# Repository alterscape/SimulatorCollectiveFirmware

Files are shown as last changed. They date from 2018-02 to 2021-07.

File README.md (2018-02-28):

# Simulator Collective Firmware

This repo contains firmware for a DIY simulator collective. The intent is not to commercialize, but rather to design something usable that an interested hobbyist with a relatively limited fabrication setup (ie: yours truly) can build and customize. Because I'm an aviation simulation enthusiast who likes physically correct (or as close as I can get for affordable prices) switchology, the "head" or "button box" component is designed to be interchangeable to support different airframes' controls. So far there are two software components:

## Collective Base

This firmware is intended to run on a Teensy 3.x, with the Joystick USB profile. It uses a contactless hall effect sensor to measure the collective arm's angle, and integrates input from the interchangeable button box. In future hardware/software revisions I hope to connect a twist throttle and collective brake as well.

## Collective Button Box

This firmware interfaces switches with the Base as an I2C slave. I probably could've used 74HC165 shift registers, like the Thrustmaster Cougar/Warthog, and just put all the brains in the Collective Base, but I like the idea of being able to support joystick axes (eg: for the spotlight slew control on some DCS helicopters) and for the box to be able to report things like its intended range of motion to the base.

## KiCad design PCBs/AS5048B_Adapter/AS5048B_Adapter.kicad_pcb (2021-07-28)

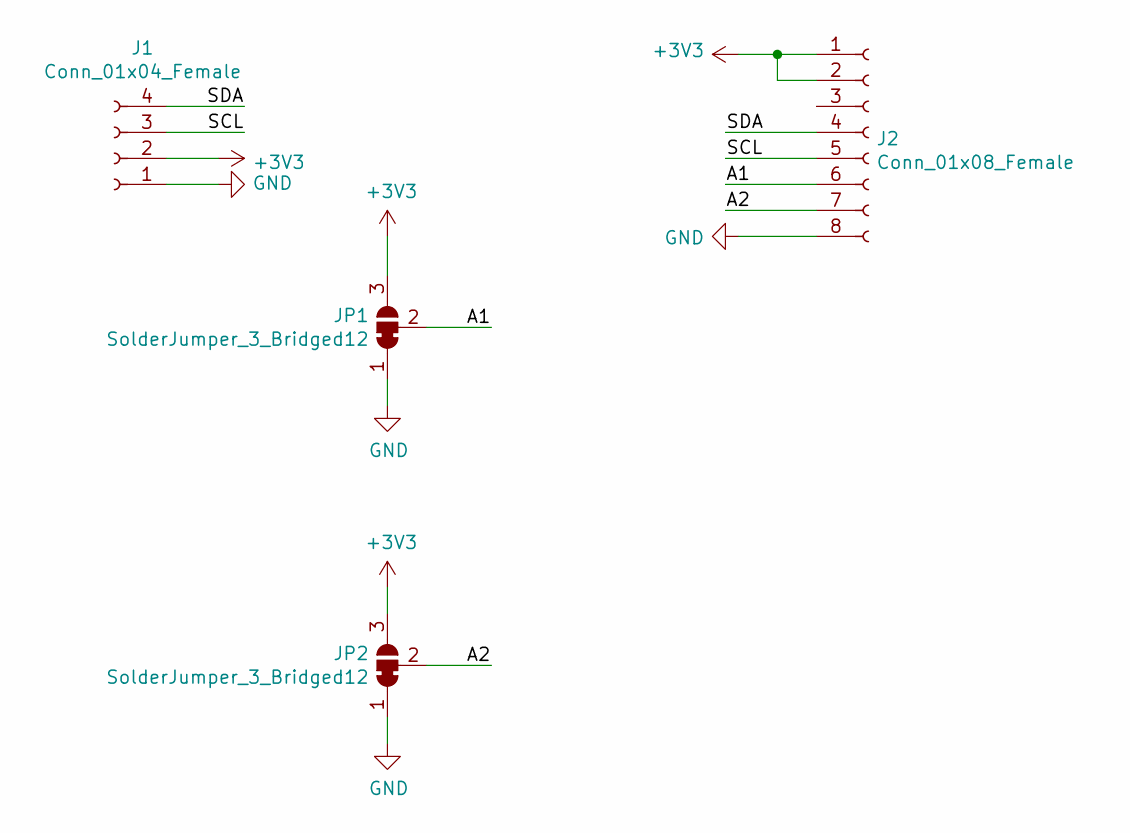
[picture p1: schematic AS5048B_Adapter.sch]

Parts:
J1: Conn_01x04_Female; Molex_PicoBlade_53047-0410_04x1.25mm_Straight
J2: Conn_01x08_Female; PinHeader_1x08_P2.54mm_Vertical
JP1, JP2: SolderJumper_3_Bridged12; SolderJumper-3_P1.3mm_Bridged12_Pad1.0x1.5mm

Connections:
+3V3: J1.2, J2.1, J2.2, JP1.3 (B), JP2.3 (B)
/A1: J2.6, JP1.2 (C)
/A2: J2.7, JP2.2 (C)
/SCL: J1.3, J2.5
/SDA: J1.4, J2.4
GND: J1.1, J2.8, JP1.1 (A), JP2.1 (A)

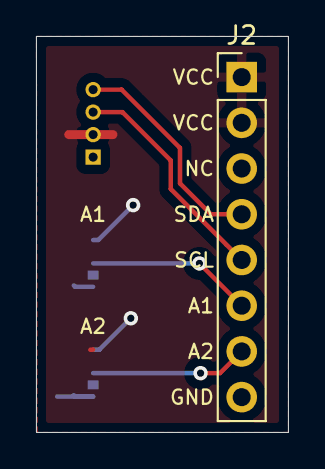
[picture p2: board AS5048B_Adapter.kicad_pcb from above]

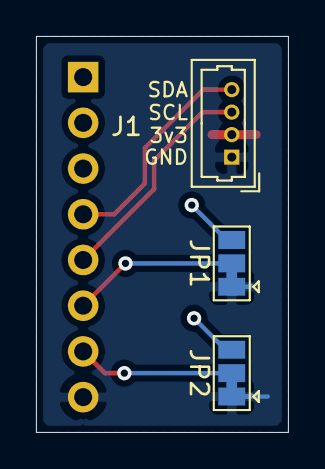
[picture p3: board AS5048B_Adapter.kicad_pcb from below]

Board: 2 copper layers, 14.0 x 22.0 mm, 4 parts (3 on the bottom side), 6 nets.

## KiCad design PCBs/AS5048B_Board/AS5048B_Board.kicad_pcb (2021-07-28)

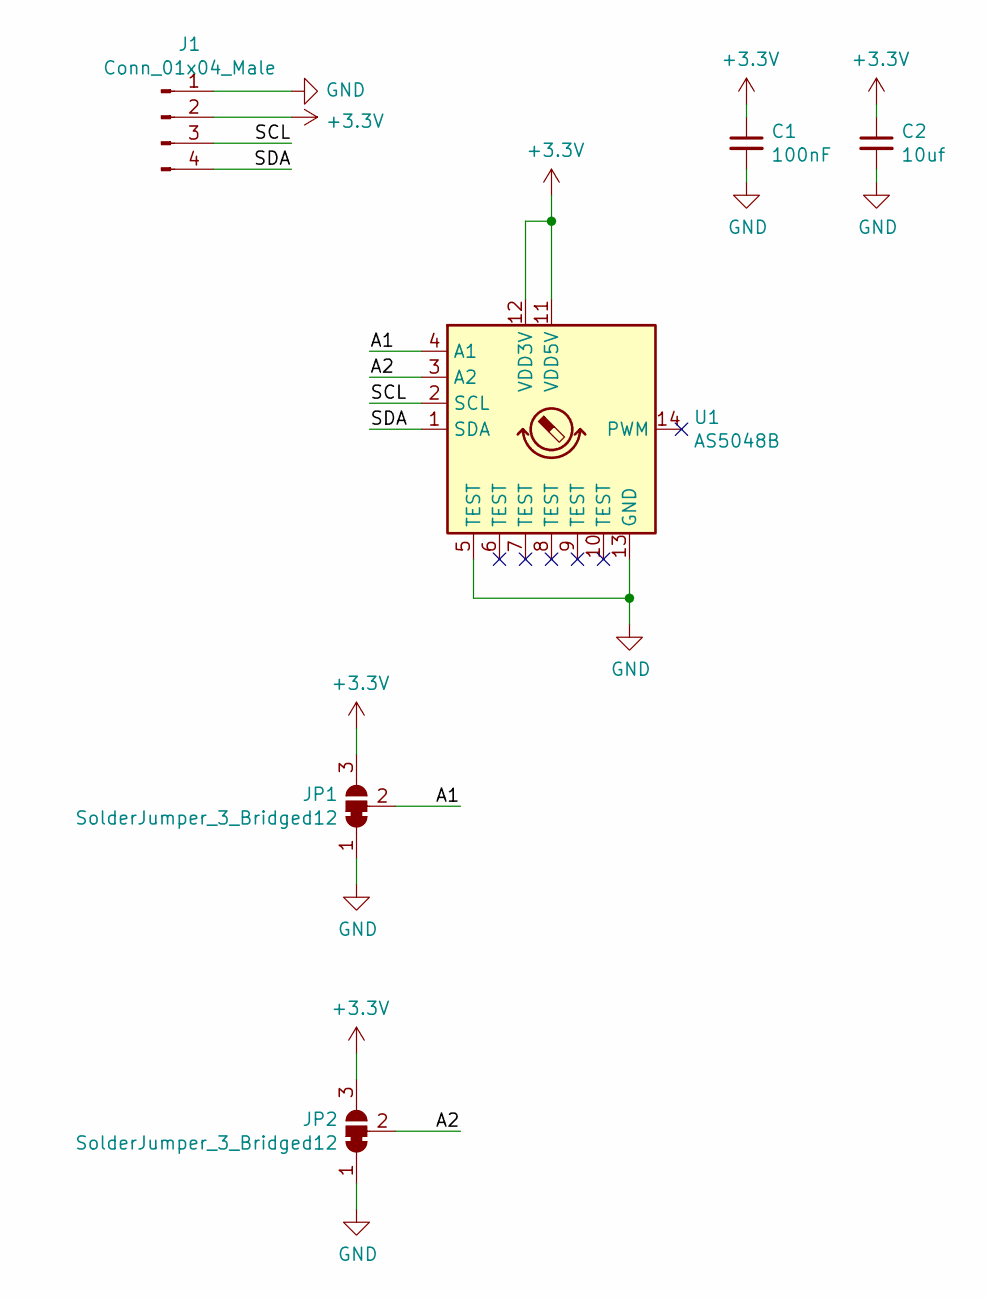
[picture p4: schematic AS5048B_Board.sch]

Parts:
C1: 100nF; C_0603_HandSoldering
C2: 10uf; C_0603_HandSoldering
J1: Conn_01x04_Male; Molex_PicoBlade_53047-0410_04x1.25mm_Straight
JP1, JP2: SolderJumper_3_Bridged12; SolderJumper-3_P1.3mm_Bridged12_Pad1.0x1.5mm
U1: AS5048B; TSSOP-14_4.4x5mm_P0.65mm

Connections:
+3V3: C1.1, C2.1, J1.2, JP1.3 (B), JP2.3 (B), U1.11 (VDD5V), U1.12 (VDD3V)
/A1: JP1.2 (C), U1.4 (A1)
/A2: JP2.2 (C), U1.3 (A2)
/SCL: J1.3, U1.2 (SCL)
/SDA: J1.4, U1.1 (SDA)
GND: C1.2, C2.2, J1.1, JP1.1 (A), JP2.1 (A), U1.5 (TEST), U1.13 (GND)

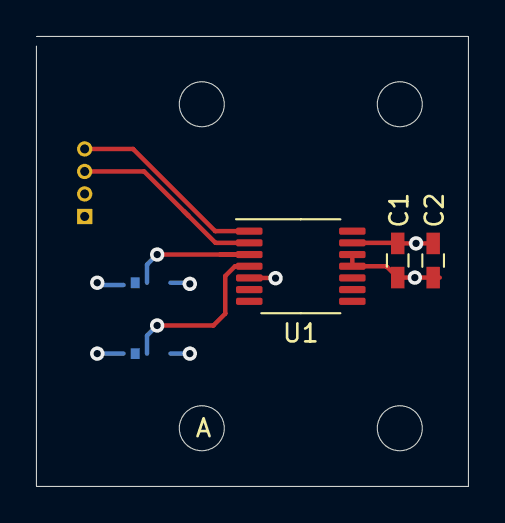
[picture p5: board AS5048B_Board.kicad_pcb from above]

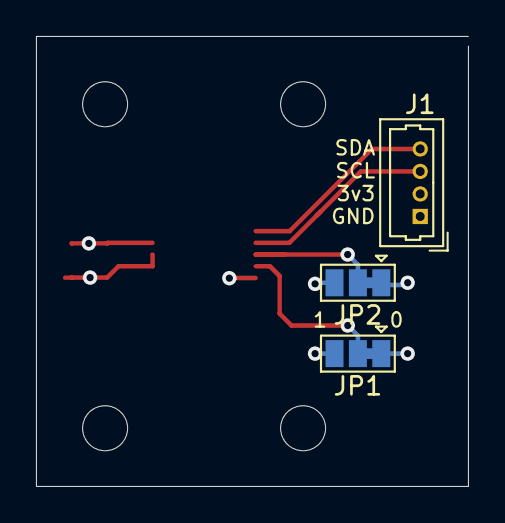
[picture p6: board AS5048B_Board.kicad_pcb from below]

Board: 4 copper layers, 24.0 x 25.0 mm, 8 parts (3 on the bottom side), 6 nets.

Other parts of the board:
A: MountingHole_2.5mm
B: MountingHole_2.5mm

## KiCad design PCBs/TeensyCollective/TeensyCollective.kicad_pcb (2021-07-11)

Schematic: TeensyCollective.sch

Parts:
C1: 47u; CP_Elec_4x4.5
C2, C4: 0.1uf; C_0603_HandSoldering
C3, C5: 1uf; C_0603_HandSoldering
D1: 1N4001; D_DO-41_SOD81_P7.62mm_Horizontal
FB1: Tiny; R_0603_HandSoldering
H1, H2, H3: MountingHole; MountingHole_2.2mm_M2_DIN965
J1: Barrel_Jack_MountingPin; BARREL_JACK
J2, J7: Conn_01x03; Molex_PicoBlade_53047-0310_03x1.25mm_Straight
J3, J4, J6: Conn_01x04; Molex_PicoBlade_53047-0410_04x1.25mm_Straight
J5: Conn_01x02; PinHeader_1x02_P2.54mm_Vertical
Q1: FQP30N06L; TO-220
R1, R2: 470; R_0603_HandSoldering
R3: R_Small_US; R_0603_HandSoldering
R4: 10k; R_0603_HandSoldering
R5, R6: 0; R_0603_HandSoldering
U1: Teensy3.2; Teensy30_31_32_LC_EDGE_ONLY

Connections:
+3V3: C2.1, C5.1, J2.2, J3.2, J4.2, J6.2, J7.2, R1.1, R2.2, U1.31
+5V: C1.1, D1.1, FB1.1, J1.1, J5.1
/BRAKE_PWM: R3.2, U1.8
/I1: J2.3, R6.1
/I2: J7.3, R5.2
/SCL: J3.3, J4.3, J6.3, R2.1, U1.26
/SDA: J3.4, J4.4, J6.4, R1.2, U1.25
GND: C1.2, C2.2, C3.2, C4.2, C5.2, J1.2, J2.1, J3.1, J4.1, J6.1, J7.1, Q1.3, R4.1, U1.1
unnamed: C3.1, C4.1, FB1.2, U1.33
unnamed: D1.2, J5.2, Q1.2
unnamed: Q1.1, R3.1, R4.2
unnamed: R5.1, U1.9
unnamed: R6.2, U1.10

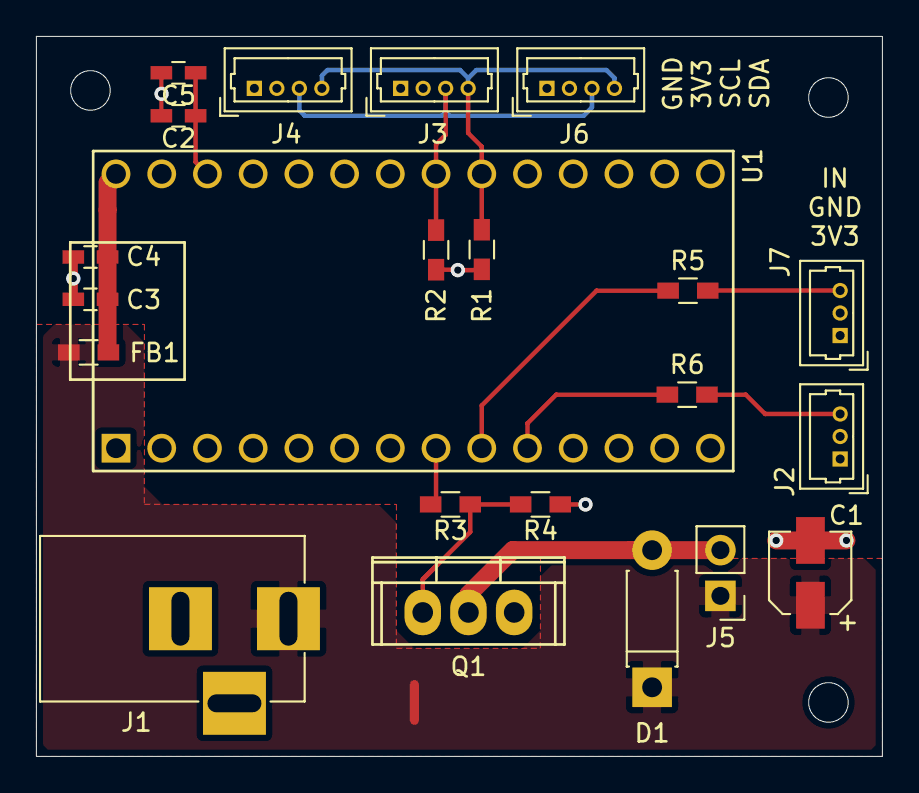
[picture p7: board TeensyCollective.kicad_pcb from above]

Board: 4 copper layers, 47.0 x 40.0 mm, 25 parts (0 on the bottom side), 13 nets.

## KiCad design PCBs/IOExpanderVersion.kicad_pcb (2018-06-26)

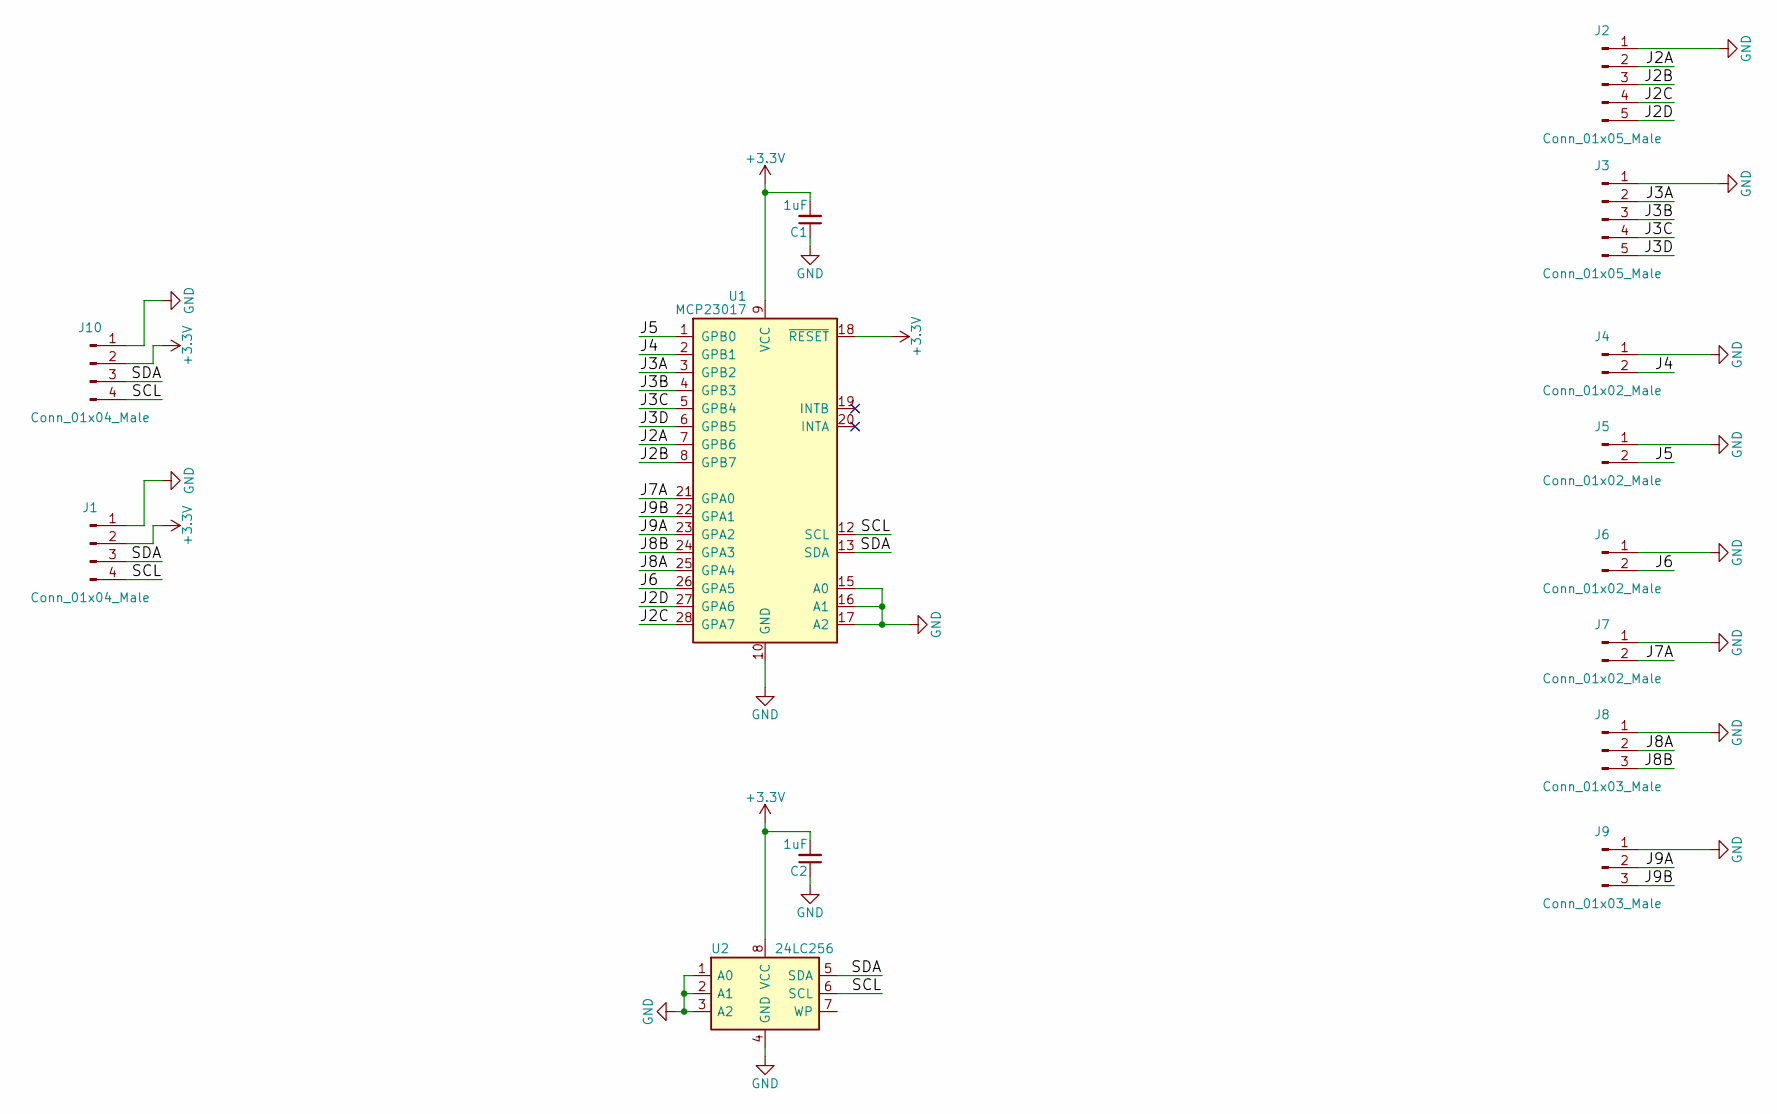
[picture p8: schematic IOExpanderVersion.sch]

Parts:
C1, C2: 1uF; C_0805_HandSoldering
J1, J10: Conn_01x04_Male; Molex_PicoBlade_53047-0410_04x1.25mm_Straight
J2, J3: Conn_01x05_Male; Molex_PicoBlade_53047-0510_05x1.25mm_Straight
J4, J5, J6, J7: Conn_01x02_Male; Molex_PicoBlade_53047-0210_02x1.25mm_Straight
J8, J9: Conn_01x03_Male; Molex_PicoBlade_53047-0310_03x1.25mm_Straight
U1: MCP23017; SOIC-28
U2: 24LC256; SOIC-8_3.9x4.9mm_Pitch1.27mm

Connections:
+3V3: C1.2, C2.2, J1.2, J10.2, U1.9 (VCC), U1.18 (~RESET), U2.8 (VCC)
/J2A: J2.2, U1.7 (GPB6)
/J2B: J2.3, U1.8 (GPB7)
/J2C: J2.4, U1.28 (GPA7)
/J2D: J2.5, U1.27 (GPA6)
/J3A: J3.2, U1.3 (GPB2)
/J3B: J3.3, U1.4 (GPB3)
/J3C: J3.4, U1.5 (GPB4)
/J3D: J3.5, U1.6 (GPB5)
/J4: J4.2, U1.2 (GPB1)
/J5: J5.2, U1.1 (GPB0)
/J6: J6.2, U1.26 (GPA5)
/J7A: J7.2, U1.21 (GPA0)
/J8A: J8.2, U1.25 (GPA4)
/J8B: J8.3, U1.24 (GPA3)
/J9A: J9.2, U1.23 (GPA2)
/J9B: J9.3, U1.22 (GPA1)
/SCL: J1.4, J10.4, U1.12 (SCL), U2.6 (SCL)
/SDA: J1.3, J10.3, U1.13 (SDA), U2.5 (SDA)
GND: C1.1, C2.1, J1.1, J2.1, J3.1, J4.1, J5.1, J6.1, J7.1, J8.1, J9.1, J10.1, U1.10 (GND), U1.15 (A0), U1.16 (A1), U1.17 (A2), U2.1 (A0), U2.2 (A1), U2.3 (A2), U2.4 (GND)

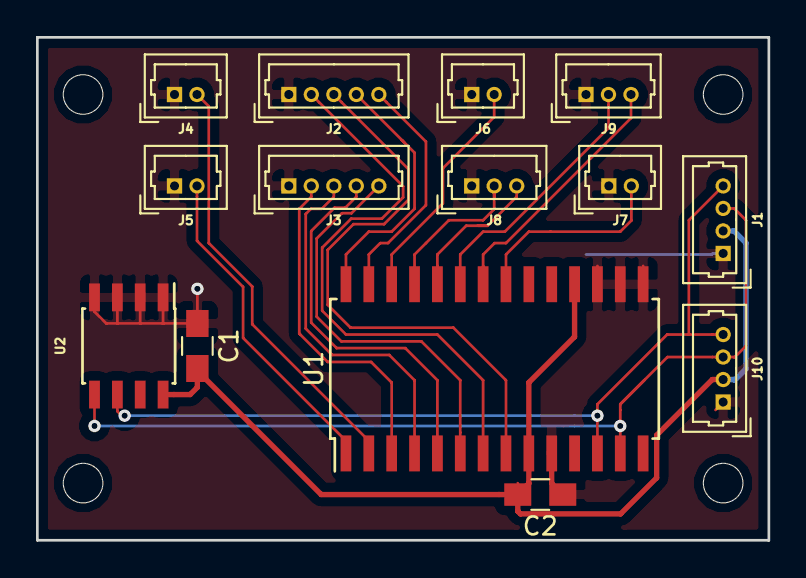
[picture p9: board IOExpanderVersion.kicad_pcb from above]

Board: 2 copper layers, 40.6 x 27.9 mm, 14 parts (0 on the bottom side), 20 nets.

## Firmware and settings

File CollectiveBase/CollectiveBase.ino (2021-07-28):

/**************************************************************************/
/*!
    @file     angle_moving_avg.ino
    @author   SOSAndroid (E. Ha.)
    @license  BSD (see license.txt)

  read over I2C bus and averaging angle

    @section  HISTORY

    v1.0 - First release
*/
/**************************************************************************/

#define SERIAL_DEBUG

//unit consts
#define U_DEG 3
#define DAMPER_PWM_PIN 6 

#include <ams_as5048b.h>
#include <Adafruit_MCP23017.h> 
// Note: download the latest from https://github.com/ppedro74/Arduino-SerialCommands and install in Documents/Arduino/libraries.
// The latest changes fix warnings in the version available through the Arduino Library Manager.
#include <SerialCommands.h>


AMS_AS5048B _collective_angle;
// IO expander
Adafruit_MCP23017 _io;

// Angle limits for collective arm.
const double _angle_min = 197.5;
double _angle_range = 30;
double _angle_max = _angle_min + _angle_range;

// Keep track of button press/releases by tracking the switch state.
uint16_t prev_switch_state = 0;

// Buffer for serial command library.
char _serial_command_buffer[32];

// Current setting for brake PWM.
uint8_t _brake_pwm = 192;

// PWM frequency for brake/damper control.
const float BRAKE_PWM_FREQ = 100;

// Tracks time since collective arm has moved.
elapsedMillis _brake_timeout;
// The collective position to compare to for brake timeout.
int16_t _brake_timeout_angle = 0;
// The amount the collective must move before we reset the brake timeout.
uint16_t _brake_timeout_tolerance = 10;
// Brake will disable if position does not change for this many millis.
uint32_t _brake_timeout_millis = 1000 * 15;
// Is the brake enabled?
bool _is_brake_enabled = false;

// Store the collective arm position.
int16_t _collective_arm_angle = 0;

// Debug flags
bool _debug_angle = true;
bool _debug_buttons = true;

SerialCommands _serial_commands(&Serial, _serial_command_buffer, sizeof(_serial_command_buffer), "\n", " ");

// This is the default handler, and gets called when no other command matches. 
// Note: It does not get called for one_key commands that do not match
void cmd_unrecognized(SerialCommands* sender, const char* cmd)
{
  sender->GetSerial()->print("Unrecognized command [");
  sender->GetSerial()->print(cmd);
  sender->GetSerial()->println("]");
}


// Sets the resistance of the collective brake when the brake is set.
void cmd_resistance_brake_on(SerialCommands* sender)
{
  // Note: Every call to Next moves the pointer to next parameter
  char* pwm_str = sender->Next();
  if (pwm_str == NULL)
  {
    sender->GetSerial()->println("ERROR NO_PWM");
    return;
  }
  int brake_pwm = atoi(pwm_str);
  set_brake_pwm(brake_pwm);
  sender->GetSerial()->print("New brake PWM: ");
  sender->GetSerial()->println(brake_pwm);
}

// Sets the range of angles for the collective arm.
void cmd_angle_range(SerialCommands* sender)
{
  // Note: Every call to Next moves the pointer to next parameter
  char* pwm_str = sender->Next();
  if (pwm_str == NULL)
  {
    sender->GetSerial()->println("ERROR NO_PWM");
    return;
  }
  float angle_range = atof(pwm_str);
  set_angle_range(angle_range);
  sender->GetSerial()->print("New angle range: ");
  sender->GetSerial()->println(angle_range);
}

void _update_brake_pwm()
{
  if (_is_brake_enabled)
  {
    analogWrite(DAMPER_PWM_PIN, _brake_pwm);
  } else {
    analogWrite(DAMPER_PWM_PIN, 0);
  }
}

// Update applied brake PWM.
void set_brake_pwm(uint8_t brake_pwm)
{
  _brake_pwm = brake_pwm;
  _update_brake_pwm();
}

// Update angle range for collective arm.
void set_angle_range(double new_range)
{
  _angle_range = new_range;
  _angle_max = _angle_min + _angle_range;
}

void set_brake_enable(bool is_enabled)
{
  if (is_enabled != _is_brake_enabled)
  {
    _is_brake_enabled = is_enabled;
    Serial.print("Brake enable? ");
    Serial.print(_is_brake_enabled);
    Serial.println();
    _update_brake_pwm();
  }
}

SerialCommand _cmd_brake("BRAKE", cmd_resistance_brake_on);
SerialCommand _cmd_angle_range("RANGE", cmd_angle_range);

void setup() {

  //Start serial
  Serial.begin(9600);
  while (!Serial) ; //wait until Serial ready

  //Start Wire object. Unneeded here as this is done (optionally) by AMS_AS5048B object (see lib code - #define USE_WIREBEGIN_ENABLED)
  Wire.begin();

  setup_as5048b();

  setup_io();

  analogWriteFrequency(DAMPER_PWM_PIN, BRAKE_PWM_FREQ);
  set_brake_pwm(192);
  set_angle_range(30);

  _serial_commands.SetDefaultHandler(cmd_unrecognized);
  _serial_commands.AddCommand(&_cmd_brake);
  _serial_commands.AddCommand(&_cmd_angle_range);
}

void setup_as5048b()
{
  //init AMS_AS5048B object
  _collective_angle.begin();

  //set clock wise counting
  _collective_angle.setClockWise(false);
}

// set up the IO expander..
void setup_io()
{  
  _io.begin();
  for (int i = 0; i < 16; i++)
  {
    _io.pullUp(i, HIGH);
  }
}

uint16_t sample_as5048b()
{
  _collective_angle.updateMovingAvgExp();

  double angle = _collective_angle.angleR(U_DEG, false);
  double scaled = (angle - _angle_min) / (_angle_max - _angle_min);
  if (scaled > 1.0) scaled = 1.0;
  if (scaled < 0.0) scaled = 0.0;

  uint16_t ten_bit = (uint16_t)(scaled * 1024.0);
  if (_debug_angle)
  {
    static uint16_t count;
    count++;
    if (count % 100 == 0)
    {
      Serial.print(angle);
      Serial.print("\t");
      Serial.print(scaled);
      Serial.print("\t");
      Serial.print(ten_bit);
      Serial.print("\t");
      Serial.print(_collective_angle.getAutoGain());
      Serial.print("\t");
      Serial.print(_collective_angle.getDiagReg(),BIN);
      Serial.print("\t");
      Serial.print(_collective_angle.magnitudeR());
      Serial.println();
    }
  }

  return ten_bit;
}

void update_buttons()
{
  uint16_t switch_state = _io.readGPIOAB();
  uint16_t changes = switch_state ^ prev_switch_state;
  if (changes != 0)
  {
    for (int i = 0; i < 16; i++)
    {
      int mask = 1 << i;
      if ( ( changes & mask ) != 0 )
      {
        int new_state = (switch_state & mask) == 0;
        // Joystick buttons are indexed from 1, so add 1.
        Joystick.button(i + 1, new_state);
        if (_debug_buttons)
        {
          Serial.print("\t");
          Serial.print(i);
          Serial.print(" ");
          Serial.print(new_state ? "down" : "up");
          Serial.println();
        }
      }
    }   
  }
  prev_switch_state = switch_state;
}

void update_brake_timeout()
{
  if (abs(_collective_arm_angle - _brake_timeout_angle) > _brake_timeout_tolerance)
  {
    _brake_timeout_angle = _collective_arm_angle;
    _brake_timeout = 0;
    set_brake_enable(true);
  } 
  else if (_brake_timeout > _brake_timeout_millis)
  {
    set_brake_enable(false);
  }
}

void loop() 
{
  _serial_commands.ReadSerial();
  _collective_arm_angle = sample_as5048b();
  update_brake_timeout();
  Joystick.X(_collective_arm_angle);
  update_buttons();
  delay(10);
}

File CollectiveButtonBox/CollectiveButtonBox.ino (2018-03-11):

#include <Wire.h>
#include "I2CProtocol.h"
#include "ShiftToButtons.h"

/* Optional delay between shift register reads.
*/
#define POLL_DELAY_MSEC   1

int argsCnt = 0;                        // how many arguments were passed with given command
Commands::I2CCommand requestedCmd = 0;  // which command was requested (if any)

uint8_t i2cArgs[I2C_MSG_ARGS_MAX];      // array to store args received from master
int i2cArgsLen = 0;                     // how many args passed by master to given command

uint8_t i2cResponse[I2C_RESP_LEN_MAX];  // array to store response
int i2cResponseLen = 0;                 // response length

ShiftButtons buttons = ShiftButtons();

void loopI2C()
{
  switch(requestedCmd)
  {
    case Commands::I2C_CMD_GET_BUTTONS:
      i2cResponseLen = 0;
      i2cResponseLen++;
      i2cResponse[i2cResponseLen - 1] = buttons.pinValues >> 24 & 0xFF;
      i2cResponseLen++;
      i2cResponse[i2cResponseLen - 1] = buttons.pinValues >> 16 & 0xFF;
      i2cResponseLen++;
      i2cResponse[i2cResponseLen - 1] = buttons.pinValues >> 8 & 0xFF;
      i2cResponseLen++;
      i2cResponse[i2cResponseLen - 1] = buttons.pinValues & 0xFF;
      break;
    default:
      // do nothing.
      break;
  }
  requestedCmd = 0;
}

void requestEvent(){
  Wire.write(i2cResponse, i2cResponseLen);
}

void receiveEvent(int bytesReceived){
  int cmdRcvd = -1;
  int argIndex = -1; 
  argsCnt = 0;

  if (Wire.available()){
    cmdRcvd = Wire.read();                 // receive first byte - command assumed
    while(Wire.available()){               // receive rest of tramsmission from master assuming arguments to the command
      if (argIndex < I2C_MSG_ARGS_MAX){
        argIndex++;
        i2cArgs[argIndex] = Wire.read();
      }
      else{
        ; // implement logging error: "too many arguments"
      }
      argsCnt = argIndex+1;  
    }
  }
  else{
    // implement logging error: "empty request"
    return;
  }
  // validating command is supported by slave
  int fcnt = -1;
  for (int i = 0; i < sizeof(supportedI2Ccmd); i++) {
    if (supportedI2Ccmd[i] == cmdRcvd) {
      fcnt = i;
    }
  }

  if (fcnt<0){
    // implement logging error: "command not supported"
    return;
  }
  requestedCmd = cmdRcvd;
}  

void setup()
{
    Wire.begin(SLAVE_ADDRESS);
    Wire.onRequest(requestEvent);
    Wire.onReceive(receiveEvent);
    Serial.begin(57600);

    Serial.println("Hello world");

    buttons.setup();
}

void loop()
{
    /* Read the state of all zones.
    */
    buttons.pinValues = buttons.read_shift_regs();

    /* If there was a chage in state, display which ones changed.
    */
    if(buttons.pinValues != buttons.oldPinValues)
    {
        Serial.print("*Pin value change detected*\r\n");
        buttons.display_pin_values();
        buttons.oldPinValues = buttons.pinValues;
    }
    loopI2C();
    delay(POLL_DELAY_MSEC);
}

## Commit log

2018-02-28 Added readme and Arduino sketches.
2018-03-11 Add I2C protocol for interchangeable button boxes.
    Super simple for now, but room to grow!
2018-06-26 The version I actually sent to fab!
    [IOExpanderVersion.kicad_pcb, IOExpanderVersion.sch, _saved_IOExpanderVersion.sch]
2019-04-14 Split angle sensor and GPIO into methods. Fixed GPIO.
    [CollectiveBase.ino]
2019-04-14 Updated to new kicad 5.x
    [IOExpanderVersion.sch]
2021-07-11 Initial commit of TeensyCollective v0
    [TeensyCollective.kicad_pcb, TeensyCollective.sch]
2021-07-28 Add serial control for range and brake strength; iterate PCBs.
    [AS5048B_Adapter.kicad_pcb, AS5048B_Adapter.sch, AS5048B_Board.kicad_pcb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]
